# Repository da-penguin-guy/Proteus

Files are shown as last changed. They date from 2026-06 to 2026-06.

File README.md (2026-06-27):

# The Proteus

The Proteus is a modular collection of PCBs that will be used to develop the Virgil sound Protocol

Formerly known as the Virgil Controller, the Proteus is named after Proteus, a minor god from greek mythology. I chose this name because in Virgil's Georgics, he rapidly changes form, similar to how the Proteus is fully modular and can change quickly.

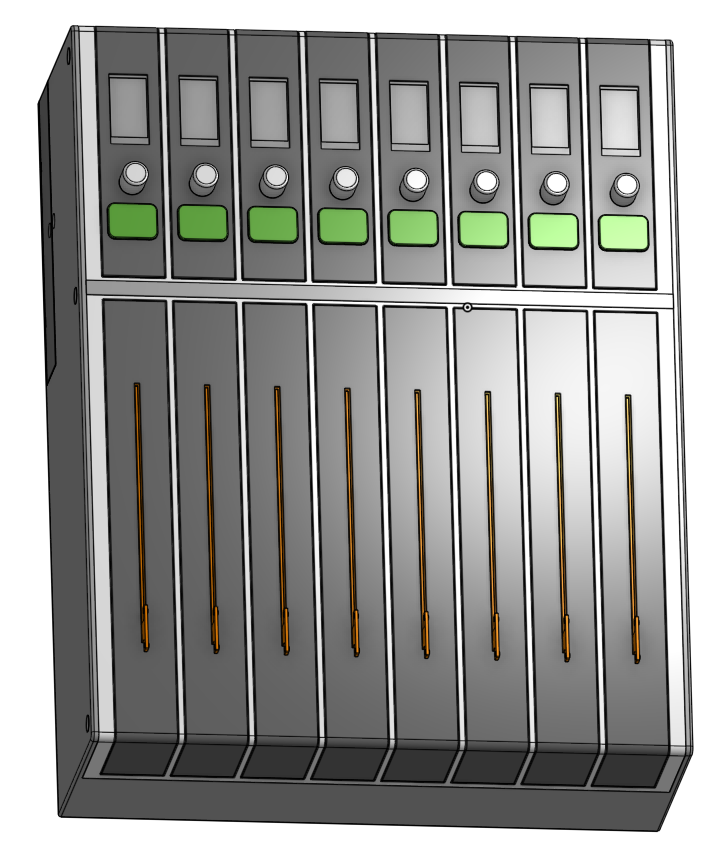
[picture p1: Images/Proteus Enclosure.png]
Proteus Enclosure


## Overview

The Proteus doesn't fall into a good product class, primarily because this hasn't ever been done before. The best analog would be some midi controller, like the [Behringer X-touch](https://www.behringer.com/en/products/0808-AAE). However, this varies from that in several cases. Firstly, it will be fully open source, modular, and future proof. The other main difference is that it won't be using the MIDI protocol. I will be using this as a hardware prototype to develop the [Virgil](https://github.com/da-penguin-guy/Virgil) live sound protocol. 

The Virgil protocol is a companion protocol to Audinate's Dante protocol, the industry standard for live audio transfer via a network. However, there is a significant gap in Dante: It only encompasses the audio transportation, not any additional communication. This is especially important for digital stageboxes, where the mixer *needs* control over physical hardware controls such as gain and phantom power. Because Dante doesn't allow for control packets, every popular audio company has created their own proprietary standard for transporting the information. This means that, despite Dante's goal of allowing for equipment from different companies to work together, productions are still limited to a single brand if they want a functional ecosystem. 

The Virgil protocol solves this by being a universal language, allowing a variety of interconnectivity.

## Modules

Cursor: Motor
Speculum: Screen
Ordo: Button

The controller itself has 16 module slots, 8 on the bottom and 8 on the top. Electrically, the slots are identical, but the slots have different lengths.

All modules (at this time) must have an rp2040/2350 microcontroller in them, and all communication over SPI.

Currently, the only module for the top slot is a display module that has a 1.14" TFT display, a button with a neopixel, and a continuous encoder with a neopixel. The display is the same as the [Adafruit Newxie Tube](https://www.adafruit.com/product/6113), but just the panel can be found on [AliExpress](https://www.aliexpress.com/i/3256803593005387.html?gatewayAdapt=4itemAdapt#nav-description) for significantly cheaper. For more information, go to the [Proteus Speculum](PCB/Proteus%20Speculum/Virgil%20Screen.kicad_pro) kicad project.

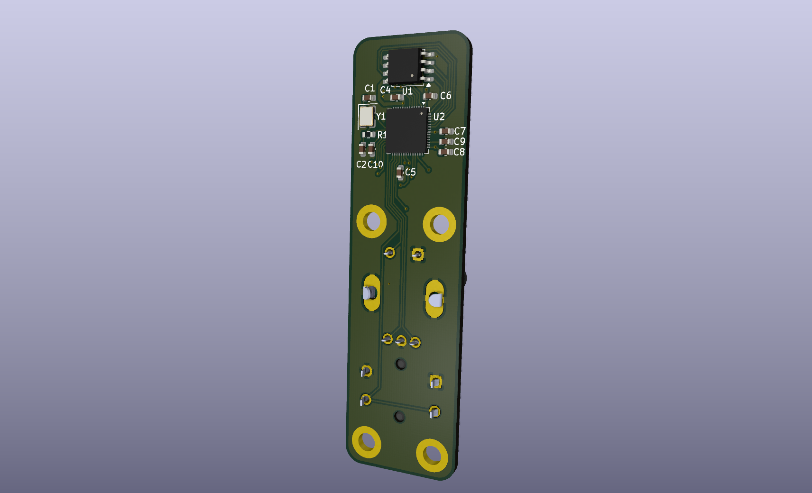
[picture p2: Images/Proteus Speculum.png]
Proteus Speculum Rendering


Currently, the only module for the bottom slot is a motorized fader using the B103 fader. These are the same faders used in the [Behringer X-Touch](https://www.sweetwater.com/store/detail/XTOUCHFADER--behringer-mf100t-motorized-faders-set-of-5-for-by-touch-series), but they can be found for significantly cheaper on [Alibaba](https://www.alibaba.com/product-detail/Toy-Sound-Box-Variable-Resistors-Fader_1601226018682.html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). For more information, go to the [Proteus Cursor](PCB/Proteus%20Cursor/Virgil%20Motor.kicad_pro) kicad project.

## Internal PCBs

The Proteus has 3 internal PCBs: The [Motherboard](#motherboard), The [Power](#power) Board, and The [Backplane](#backplane).

### Motherboard
This is the actual brain of the device.

For external ports, it has an Ethercon port for networking and a USB-C port for programming.  

For Internal ports, it has 2 50 pin IDC connectors, each with different pinouts. The first connects to the Power board and the second connects to the Backplane. The power board connects directly to the Controller, while the backplane connects via an IDC cable. There is also a microSD card connected via SDIO for icon storage.

For ICs the controller has an RP2350. It also has a W5500 for ethernet connectivity and the Raspberry Pi Radio Module 2 for wireless connectivity

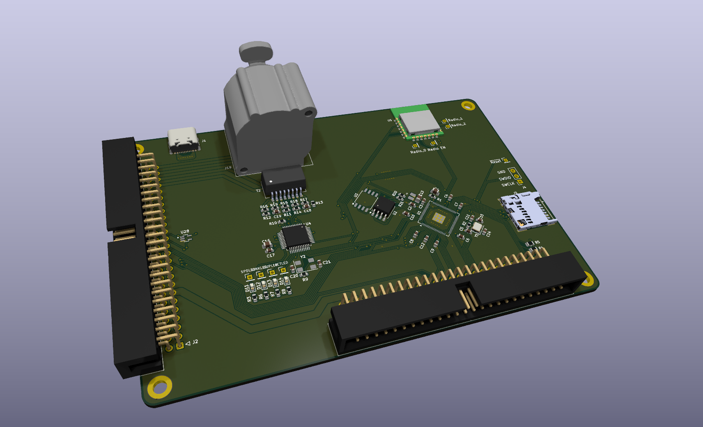
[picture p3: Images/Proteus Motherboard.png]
Proteus Motherboard Rendering


### Power
The power module is designed to be completely separated and isolated from the main board. This is primarily because I want for this to eventually have a battery powered option, but I don't want to deal with a BMS yet. 

The power module is expected to supply 3.3V, 5V, and a currently unknown motor VCC (somewhere between 9-12V). Motor VCC and current requirements will be determined after testing

Power modules are given a space on the back of the enclosure to expose their own power connectors. In addition, all the required signals for POE and USB-C PD are passed from the controller to the power board, including USB-C CC lines.

Currently, the only power module that has been developed supports POE and 12V in through a barrel jack. This power module is designed to be for very early prototyping. Because of that, the current module has an RP2350 on it, combined with current and voltage sensing on all lines. In addition, the motor VCC also has a smart power fuse and adjustable voltage via a DigiPot.

### Backplane
The backplane is the PCB that the modules plug into. This is kept separate so that extra module slots may be added in the future, and for simplifying enclosure design. 

The main purpose of the backplane is to route connections from the 50 pin connector to the controller and each of the 16 modules. The signals that are being routed are various power lines, spi, SWD, and one singular GPIO. That gpio is tied directly to the controller, and was intended as an SPI interrupt. However, that will likely be removed in future iterations to allow for better scaling across more modules.

The backplane does have some ICs on it. The most notable is a CD74HC154M96, used to split the 4 CS mux lines from the controller to 16 CS lines for the modules. There are also 2 MCP23017T-E/SS I2C expanders, used for supplying reset lines to the modules and detect lines. The backplane also has 16 SN74CBTLV1G125DCKR, one for each module. This is used to switch the SWD lines on or off for each module, using the CS line as the control signal. This is so that the controller can program every module automatically.

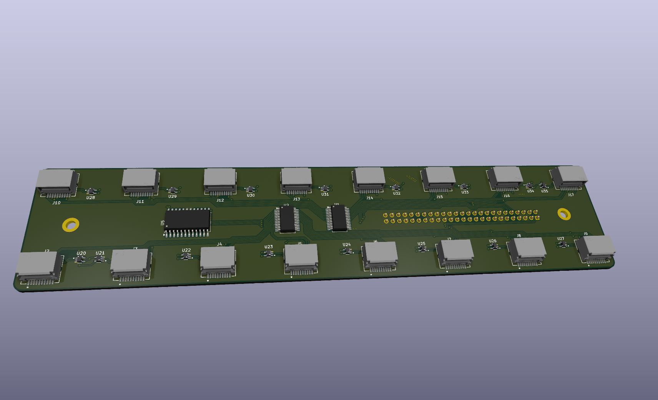
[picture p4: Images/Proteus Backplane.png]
Proteus Backplane Rendering


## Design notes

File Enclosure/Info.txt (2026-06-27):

All 3d models were made in onshape. The link can be found here: https://cad.onshape.com/documents/d399654ec14494d1790123eb/w/8a950a518b7c39473549627b/e/b128ff8ea3088b92f5d37e80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

The size of all heat set inserts can be adjusted in the variable studio.

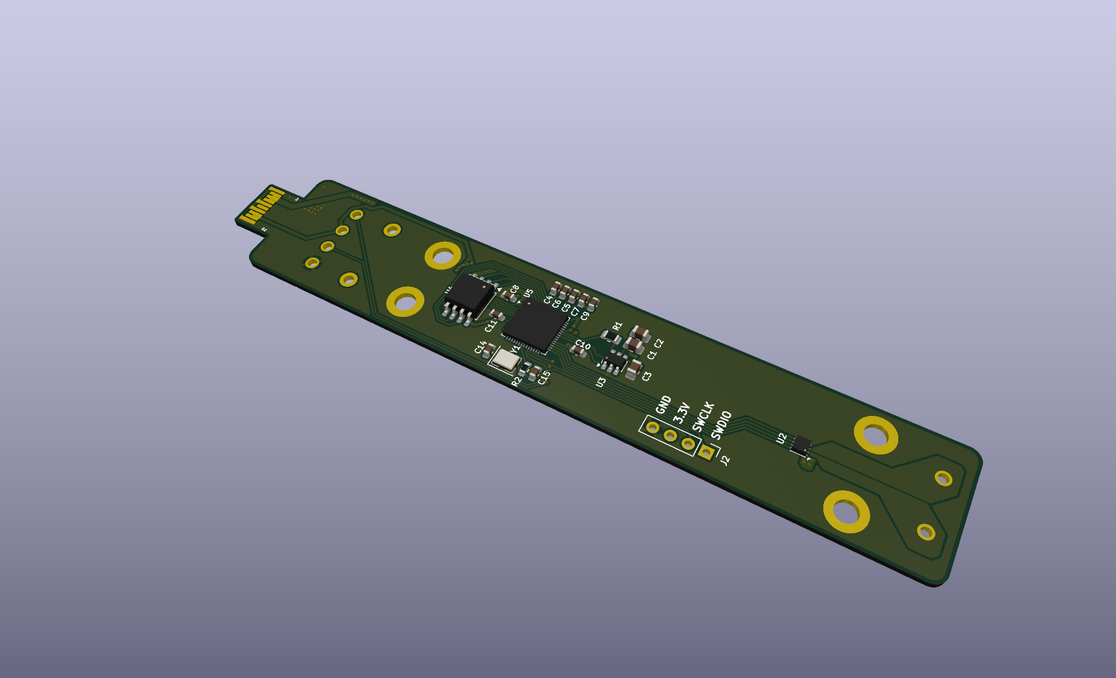
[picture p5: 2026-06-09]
Images/Proteus Cursor.png

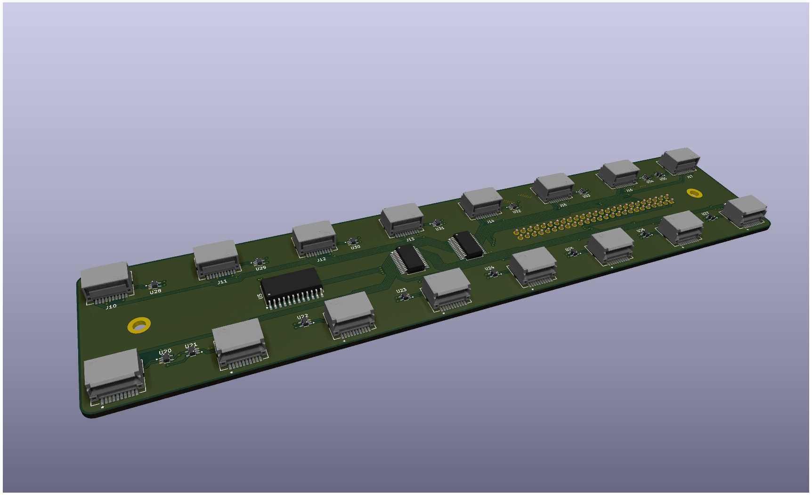
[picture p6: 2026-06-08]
PCB/Proteus Backplane/render.png

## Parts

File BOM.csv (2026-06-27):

Name | Count | Category | File/Link
Proteus Motherboard | 1 | PCB | PCB\Proteus Motherboard
Proteus Backplane | 1 | PCB | PCB\Proteus Backplane
Proteus Power | 1 | PCB | PCB\Proteus Power
Proteus Spectulum | 8 | PCB | PCB\Proteus Speculum
Ribbon Adaptor | 8 | PCB | PCB\Ribbon Adaptor
Proteus Cursor | 8 | PCB | PCB\Proteus Cursor
1.14" TFT Display | 8 | Non PCB Electronics | https://www.aliexpress.com/i/3256803593005387.html?gatewayAdapt=4itemAdapt#nav-description
Base | 1 | Enclosure | Enclosure\Part Studio 1.step
Power Slide | 1 | Enclosure | Enclosure\Part Studio 1.step
Lock Pin | 1 | Enclosure | Enclosure\Part Studio 1.step
Fader Rail | 1 | Enclosure | Enclosure\Part Studio 1.step
Midplate | 1 | Enclosure | Enclosure\Part Studio 1.step
Screen Rail | 1 | Enclosure | Enclosure\Part Studio 1.step
Fader Container Lid | 8 | Enclosure | Enclosure\Part Studio 1.step
Fader Container | 8 | Enclosure | Enclosure\Part Studio 1.step
Screen Container Lid | 8 | Enclosure | Enclosure\Part Studio 1.step
Screen Container | 8 | Enclosure | Enclosure\Part Studio 1.step
Knob | 8 | Enclosure | Enclosure\Part Studio 1.step
Button | 8 | Enclosure | Enclosure\Part Studio 1.step
Display Case | 8 | Enclosure | Enclosure\Virgil Screen.step
M3x5x5 Heat set insert | 198 | Part
M3 Countersunk screw | 198 | Part

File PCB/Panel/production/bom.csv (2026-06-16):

Designator | Footprint | Quantity | Value | LCSC Part #
C1, C11, C13, C2, C24, C26, C33, C34 | 0603 | 8 | 15pF
C10, C12, C14, C15, C16, C17, C18, C19, C20, C21, C22, C23, C25, C27, C28, C29, C3, C30, C31, C32, C35, C36, C37, C38, C4, C5, C6, C7, C8, C9 | 0603 | 30 | 100nF
D1, D2, D3, D4 | LED_SK6812MINI_PLCC4_3.5x3.5mm_P1.75mm | 4 | SK6812MINI
J1, J2, J3, J4 | JUSHUO AFC07-S20FCC-00 | 4 | AFC07-S20FCC-00
J10, J9 | PinHeader_1x04_P2.54mm_Vertical | 2 | Conn_01x04_Pin
J5, J6, J7, J8 | 10056847-101LF-EDGE | 4 | 10056847-101LF
Q1, Q2 | SOT-23 | 2 | SS8550
R1, R2, R3, R4 | 0603 | 4 | 1kΩ
S1, S2 | XDCR_PEC12R-4225F-S0024 | 2 | PEC12R-4225F-S0024
S3, S4 | SW_B3F-4055 | 2 | B3F-4055
U1, U2 | SOT-23-6 | 2 | SN74LVC1T45DBV
U10, U9 | WSON-8-1EP_2x2mm_P0.5mm_EP0.9x1.6mm_ThermalVias | 2 | DRV8220DSG
U11, U12, U15, U16 | QFN-56-1EP_7x7mm_P0.4mm_EP3.2x3.2mm | 4 | RP2040
U13, U14 | SOIC8_4P9X3P9MC_MCH-L | 2 | CAP1293-1-SN-TR
U17, U18, U7, U8 | SOIC-8_5.3x5.3mm_P1.27mm | 4 | W25Q16JVSS
U3, U4 | B103 | 2 | B103
U5, U6 | Display Connector | 2 | AFC07-S08ECC-00
Y1, Y2, Y3, Y4 | Crystal_SMD_Abracon_ABM8G-4Pin_3.2x2.5mm | 4 | ABM8-272-T3

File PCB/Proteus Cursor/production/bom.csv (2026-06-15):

Designator | Footprint | Quantity | Value | LCSC Part #
C10, C11, C4, C5, C6, C7, C8, C9 | 0603 | 8 | 100nF
C14, C15 | 0603 | 2 | 15pF
J1 | 10056847-101LF-EDGE | 1 | 10056847-101LF
J2 | PinHeader_1x04_P2.54mm_Vertical | 1 | Conn_01x04_Pin
R2 | 0603 | 1 | 1kΩ
U1 | B103 | 1 | B103
U2 | WSON-8-1EP_2x2mm_P0.5mm_EP0.9x1.6mm_ThermalVias | 1 | DRV8220DSG
U3 | SOIC8_4P9X3P9MC_MCH-L | 1 | CAP1293-1-SN-TR
U4 | SOIC-8_5.3x5.3mm_P1.27mm | 1 | W25Q16JVSS
U5 | QFN-56-1EP_7x7mm_P0.4mm_EP3.2x3.2mm | 1 | RP2040
Y1 | Crystal_SMD_Abracon_ABM8G-4Pin_3.2x2.5mm | 1 | ABM8-272-T3

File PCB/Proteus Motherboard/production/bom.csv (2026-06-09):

Designator | Footprint | Quantity | Value | LCSC Part #
C1, C13, C16 | 0805 | 3 | 4.7uF
C10, C11, C12, C17, C18, C2, C3, C4, C5, C6, C7, C8, C9 | 0603 | 13 | .1uF
C14, C15 | 0603 | 2 | 15pF
C19 | 0603 | 1 | 22nF
C20, C21 | 0603 | 2 | 18pF
D11, D12, D13, D14 | 0603 | 4 | LED
J1 | USB_C_Receptacle_GCT_USB4105-xx-A_16P_TopMnt_Horizontal | 1 | USB_C_Receptacle_USB2.0_16P
J19 | NEUTRIK_NE8FAH | 1 | NE8FAH
J2 | IDC-Header_2x25_P2.54mm_Horizontal | 1 | Conn_02x25_Odd_Even
J3 | MOLEX_503398-1892 | 1 | 503398-1892
J4 | PinSocket_1x03_P2.54mm_Vertical | 1 | Conn_01x03_Pin
J6 | IDC-Header_2x25_P2.54mm_Horizontal | 1 | SBH11-PBPC-D25-RA-BK
L1 | 0806 | 1 | AOTA-B201610S3R3-101-T
R1 | 0603 | 1 | 33Ω
R10 | 0603 | 1 | 12.4kΩ
R11, R12, R13, R14 | 0603 | 4 | 3.3Ω
R15, R16, R17, R18 | 0603 | 4 | 49.9kΩ
R19 | 0603 | 1 | 10Ω
R2 | 0603 | 1 | 1kΩ
R20, R21 | 0603 | 2 | 27Ω
R3, R6, R7, R8 | 0603 | 4 | 68Ω
R4, R5 | 0805 | 2 | 4.7Ω
R9 | 0603 | 1 | 1MΩ
T2 | XFMR_PT61018PEL | 1 | PT61018PEL
TP10 | PinHeader_1x01_P2.00mm_Vertical | 1 | Radio EN
TP11 | PinHeader_1x01_P2.00mm_Vertical | 1 | Radio_2
TP12 | PinHeader_1x01_P2.00mm_Vertical | 1 | Radio_1
TP15 | PinHeader_1x01_P2.00mm_Vertical | 1 | SPDLED
TP16 | PinHeader_1x01_P2.00mm_Vertical | 1 | LINKLED
TP17 | PinHeader_1x01_P2.00mm_Vertical | 1 | DUPLED
TP18 | PinHeader_1x01_P2.00mm_Vertical | 1 | ACTLED
TP78 | PinHeader_1x01_P2.00mm_Vertical | 1 | ~{Reset}
TP9 | PinHeader_1x01_P2.00mm_Vertical | 1 | Radio_0
U1 | QFN-80-1EP_10x10mm_P0.4mm_EP3.4x3.4mm | 1 | RP2350B
U2, U3 | SOIC-8_5.3x5.3mm_P1.27mm | 2 | W25Q16JVSS
U28 | SOT65P210X110-5N | 1 | SN74CBTLV1G125DCKR
U4 | LQFP-48_7x7mm_P0.5mm | 1 | W5500
U5 | rpi_rmc20452t | 1 | SC1169
Y1 | Crystal_SMD_Abracon_ABM8G-4Pin_3.2x2.5mm | 1 | ABM8-272-T3
Y2 | Crystal_SMD_Abracon_ABM3C-4Pin_5.0x3.2mm | 1 | ABM3C-25.000MHZ-D4Y-T

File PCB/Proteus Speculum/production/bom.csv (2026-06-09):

Designator | Footprint | Quantity | Value | LCSC Part #
C1, C2 | 0603 | 2 | 15pF
C10, C4, C5, C6, C7, C8, C9 | 0603 | 7 | 100nF
D1, D2 | LED_SK6812MINI_PLCC4_3.5x3.5mm_P1.75mm | 2 | SK6812MINI
J2 | AMPHENOL_SFV20R-2STE1HLF | 1 | AFC07-S20FCC-00
Q1 | SOT-23 | 1 | SS8550
R1 | 0603 | 1 | 1kΩ
S1 | XDCR_PEC12R-4225F-S0024 | 1 | PEC12R-4225F-S0024
S2 | SW_B3F-4055 | 1 | B3F-4055
U1 | SOIC-8_5.3x5.3mm_P1.27mm | 1 | W25Q16JVSS
U2 | QFN-56-1EP_7x7mm_P0.4mm_EP3.2x3.2mm | 1 | RP2040
U3 | SOT-23-6 | 1 | SN74LVC1T45DBV
U4 | Display Connector | 1 | AFC07-S08ECC-00
Y1 | Crystal_SMD_Abracon_ABM8G-4Pin_3.2x2.5mm | 1 | ABM8-272-T3

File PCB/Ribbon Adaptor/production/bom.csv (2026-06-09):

Designator | Footprint | Quantity | Value | LCSC Part #
J1 | 10056847-101LF-EDGE | 1 | 10056847-101LF
J2 | AMPHENOL_SFV20R-2STE1HLF | 1 | AFC07-S20FCC-00

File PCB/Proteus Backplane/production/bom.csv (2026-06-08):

Designator | Footprint | Quantity | Value | LCSC Part #
J1 | IDC-Header_2x25_P2.54mm_Vertical | 1 | SBH11-PBPC-D25-RA-BK
J10, J11, J12, J13, J14, J15, J16, J17, J2, J3, J4, J5, J6, J7, J8, J9 | CONN_10056847-101LF_AMP | 16 | 10056847-101LF
U1, U2 | SSOP-28_5.3x10.2mm_P0.65mm | 2 | MCP23017T-E/SS
U20, U21, U22, U23, U24, U25, U26, U27, U28, U29, U30, U31, U32, U33, U34, U35 | SOT65P210X110-5N | 16 | SN74CBTLV1G125DCKR
U5 | SOIC-24W_7.5x15.4mm_P1.27mm | 1 | CD74HC154M96

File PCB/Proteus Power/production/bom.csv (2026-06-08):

Designator | Footprint | Quantity | Value | LCSC Part #
C1, C10, C11, C12, C13, C14, C16, C18, C20, C21, C22, C24, C26, C27, C4, C6, C7, C8, C9 | 1206 | 19 | 10uF
C15, C17, C19, C2, C25, C3, C5 | 0603 | 7 | .1uF
C23 | CP_Radial_D10.0mm_P5.00mm | 1 | 1mF
D1, D2, D3, D4, D5, D6, D7, D8 | D_DO-15_P12.70mm_Horizontal | 8 | D_Schottky
J2 | BarrelJack_Horizontal | 1 | Barrel_Jack_MountingPin
J3 | CONN_SFH11-PBPC-D25-RA-BK_50P_SUL | 1 | Conn_02x25_Odd_Even
L1, L2, L3 | IND_PA4342_PUL-L | 3 | 4.7uH
R1 | 0603 | 1 | 52.3kΩ
R10, R13 | 2512 | 2 | 10mΩ
R11 | 2512 | 1 | 20mΩ
R12 | 2010 | 1 | 50mΩ
R14, R3, R7, R8 | 0603 | 4 | 10kΩ
R2 | 0603 | 1 | 30.9kΩ
R4 | 0603 | 1 | 102kΩ
R5, R6 | 0603 | 2 | 5.1kΩ
R9 | 0603 | 1 | 100kΩ
U1, U2, U4 | SOT-583-8 | 3 | TPS563300
U10, U12, U3, U8 | VSSOP-10_3x3mm_P0.5mm | 4 | INA226
U11, U9 | SO-4_4.4x3.6mm_P2.54mm | 2 | LTV-356T
U13 | TO-252-4 | 1 | BTS50080-1TEA
U5 | MODULE_AG59612-LPB | 1 | AG59612-LPB
U6 | XIAO-RP2040-SMD | 1 | XIAO-RP2040-SMD
U7 | MSOP-8_3x3mm_P0.65mm | 1 | MCP4562T-503E/MF

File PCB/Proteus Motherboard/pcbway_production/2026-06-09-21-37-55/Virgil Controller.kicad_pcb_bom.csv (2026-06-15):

Designator | Quantity | Value | Footprint | Package | MPN | DNP | Mount_Type | Description | KiLib_Generator | Sim.Pins | MF | MAXIMUM_PACKAGE_HEIGHT | Price | Check_prices | STANDARD | PARTREV | SnapEDA_Link | MP | Description_1 | MANUFACTURER | Availability | SNAPEDA_PN | DigiKey_Part_Number
C1, C13, C16 | 3 | 4.7uF | C_0805_2012Metric |  |  |  | smt | Unpolarized capacitor | SMD_2terminal_chip_molded
C10, C11, C12, C17, C18, C2, C3, C4, C5, C6, C7, C8, C9 | 13 | .1uF | C_0603_1608Metric |  |  |  | smt | Unpolarized capacitor | SMD_2terminal_chip_molded
C14, C15 | 2 | 15pF | C_0603_1608Metric |  |  |  | smt | Unpolarized capacitor | SMD_2terminal_chip_molded
C19 | 1 | 22nF | C_0603_1608Metric |  |  |  | smt | Unpolarized capacitor | SMD_2terminal_chip_molded
C20, C21 | 2 | 18pF | C_0603_1608Metric |  |  |  | smt | Unpolarized capacitor | SMD_2terminal_chip_molded
D11, D12, D13, D14 | 4 | LED | LED_0603_1608Metric |  |  |  | smt | Light emitting diode | SMD_2terminal_chip_molded | 1=K 2=A
J1 | 1 | USB_C_Receptacle_USB2.0_16P | USB_C_Receptacle_GCT_USB4105-xx-A_16P_TopMnt_Horizontal |  |  |  | smt | USB 2.0-only 16P Type-C Receptacle connector
J19 | 1 | NE8FAH | NEUTRIK_NE8FAH | None |  |  | tht |  |  |  | Neutrik | 25.00mm | None | https://www.snapeda.com/parts/NE8FAH/Neutrik/view-part/?ref=eda | Manufacturer Recommendations | 16.04.02 | https://www.snapeda.com/parts/NE8FAH/Neutrik/view-part/?ref=snap | NE8FAH | Horizonal PCB mount RJ45 receptacle, A-Series cutout with latch lock, max | Neutrik | In Stock | NE8FAH
J2 | 1 | Conn_02x25_Odd_Even | IDC-Header_2x25_P2.54mm_Horizontal |  |  |  | tht | Generic connector, double row, 02x25, odd/even pin numbering scheme (row 1 odd numbers, row 2 even numbers), script generated (kicad-library-utils/schlib/autogen/connector/)
J3 | 1 | 503398-1892 | MOLEX_503398-1892 |  |  |  | smt |  |  |  |  |  |  |  | MANUFACTURER RECOMMENDATIONS | 0 |  |  |  | molex
J4 | 1 | Conn_01x03_Pin | PinSocket_1x03_P2.54mm_Vertical |  |  | Yes | tht | Generic connector, single row, 01x03, script generated | connector/pin_header_socket
J6 | 1 | SBH11-PBPC-D25-RA-BK | IDC-Header_2x25_P2.54mm_Horizontal |  |  |  | tht | Generic connector, double row, 02x25, top/bottom pin numbering scheme (row 1: 1...pins_per_row, row2: pins_per_row+1 ... num_pins), script generated (kicad-library-utils/schlib/autogen/connector/)
L1 | 1 | AOTA-B201610S3R3-101-T | 0806 |  |  |  | smt | Inductor
R1 | 1 | 33Ω | R_0603_1608Metric |  |  |  | smt | Resistor, US symbol | SMD_2terminal_chip_molded
R10 | 1 | 12.4kΩ | R_0603_1608Metric |  |  |  | smt | Resistor, US symbol | SMD_2terminal_chip_molded
R11, R12, R13, R14 | 4 | 3.3Ω | R_0603_1608Metric |  |  |  | smt | Resistor, US symbol | SMD_2terminal_chip_molded
R15, R16, R17, R18 | 4 | 49.9kΩ | R_0603_1608Metric |  |  |  | smt | Resistor, US symbol | SMD_2terminal_chip_molded
R19 | 1 | 10Ω | R_0603_1608Metric |  |  |  | smt | Resistor, US symbol | SMD_2terminal_chip_molded
R2 | 1 | 1kΩ | R_0603_1608Metric |  |  |  | smt | Resistor, US symbol | SMD_2terminal_chip_molded
R20, R21 | 2 | 27Ω | R_0603_1608Metric |  |  |  | smt | Resistor, US symbol | SMD_2terminal_chip_molded
R3, R6, R7, R8 | 4 | 68Ω | R_0603_1608Metric |  |  |  | smt | Resistor, US symbol | SMD_2terminal_chip_molded
R4, R5 | 2 | 4.7Ω | R_0805_2012Metric |  |  |  | smt | Resistor, US symbol | SMD_2terminal_chip_molded
R9 | 1 | 1MΩ | R_0603_1608Metric |  |  |  | smt | Resistor, US symbol | SMD_2terminal_chip_molded
T2 | 1 | PT61018PEL | XFMR_PT61018PEL |  |  |  | smt |  |  |  |  | 5.65 mm |  |  | Manufacturer Recommendations | 05/14 |  |  |  | Bourns
TP10 | 1 | Radio EN | PinHeader_1x01_P2.00mm_Vertical |  |  | Yes | tht | test point
TP11 | 1 | Radio_2 | PinHeader_1x01_P2.00mm_Vertical |  |  | Yes | tht | test point
TP12 | 1 | Radio_1 | PinHeader_1x01_P2.00mm_Vertical |  |  | Yes | tht | test point
TP15 | 1 | SPDLED | PinHeader_1x01_P2.00mm_Vertical |  |  | Yes | tht | test point | connector/pin_header_socket
TP16 | 1 | LINKLED | PinHeader_1x01_P2.00mm_Vertical |  |  | Yes | tht | test point | connector/pin_header_socket
TP17 | 1 | DUPLED | PinHeader_1x01_P2.00mm_Vertical |  |  | Yes | tht | test point | connector/pin_header_socket
TP18 | 1 | ACTLED | PinHeader_1x01_P2.00mm_Vertical |  |  | Yes | tht | test point | connector/pin_header_socket
TP78 | 1 | ~{Reset} | PinHeader_1x01_P2.00mm_Vertical |  |  | Yes | tht | test point | connector/pin_header_socket
TP9 | 1 | Radio_0 | PinHeader_1x01_P2.00mm_Vertical |  |  | Yes | tht | test point
U1 | 1 | RP2350B | QFN-80-1EP_10x10mm_P0.4mm_EP3.4x3.4mm |  |  |  | smt | A microcontroller by Raspberry Pi, dual CPU architecture (ARM Cortex-M33 / RISC-V Hazard3), 150MHz, no flash, 520KB SRAM, 12 PIO state machines, VQFN-80 | package/no_lead
U2 | 1 | W25Q16JVSS | SOIC-8_5.3x5.3mm_P1.27mm |  |  |  | smt | 16Mbit / 2MiB Serial Flash Memory, Standard/Dual/Quad SPI, 2.7-3.6V, SOIC-8 (208 mil) | package/gullwing
U28 | 1 | SN74CBTLV1G125DCKR | SOT65P210X110-5N | SC70-5 Texas Instruments |  |  | smt |  |  |  | Texas Instruments |  |  | https://www.snapeda.com/parts/SN74CBTLV1G125DCKR/Texas+Instruments/view-part/?ref=eda |  |  | https://www.snapeda.com/parts/SN74CBTLV1G125DCKR/Texas+Instruments/view-part/?ref=snap | SN74CBTLV1G125DCKR | 3.3-V, 1:1 (SPST), 1-channel FET bus switch |  |  |  | 296-9110-1-ND
U3 | 1 | W25Q16JVSS | SOIC-8_5.3x5.3mm_P1.27mm |  |  | Yes | smt | 16Mbit / 2MiB Serial Flash Memory, Standard/Dual/Quad SPI, 2.7-3.6V, SOIC-8 (208 mil) | package/gullwing
U4 | 1 | W5500 | LQFP-48_7x7mm_P0.5mm |  |  |  | smt | 10/100Mb SPI Ethernet controller with TCP/IP stack, LQFP-48 | package/gullwing
U5 | 1 | SC1169 | rpi_rmc20452t |  |  |  | smt
Y1 | 1 | ABM8-272-T3 | Crystal_SMD_Abracon_ABM8G-4Pin_3.2x2.5mm |  |  |  | smt | Four pin crystal, GND on pins 2 and 4 | crystal_resonator_oscillator
Y2 | 1 | ABM3C-25.000MHZ-D4Y-T | Crystal_SMD_Abracon_ABM3C-4Pin_5.0x3.2mm |  |  |  | smt | Four pin crystal, GND on pins 2 and 4 | crystal_resonator_oscillator

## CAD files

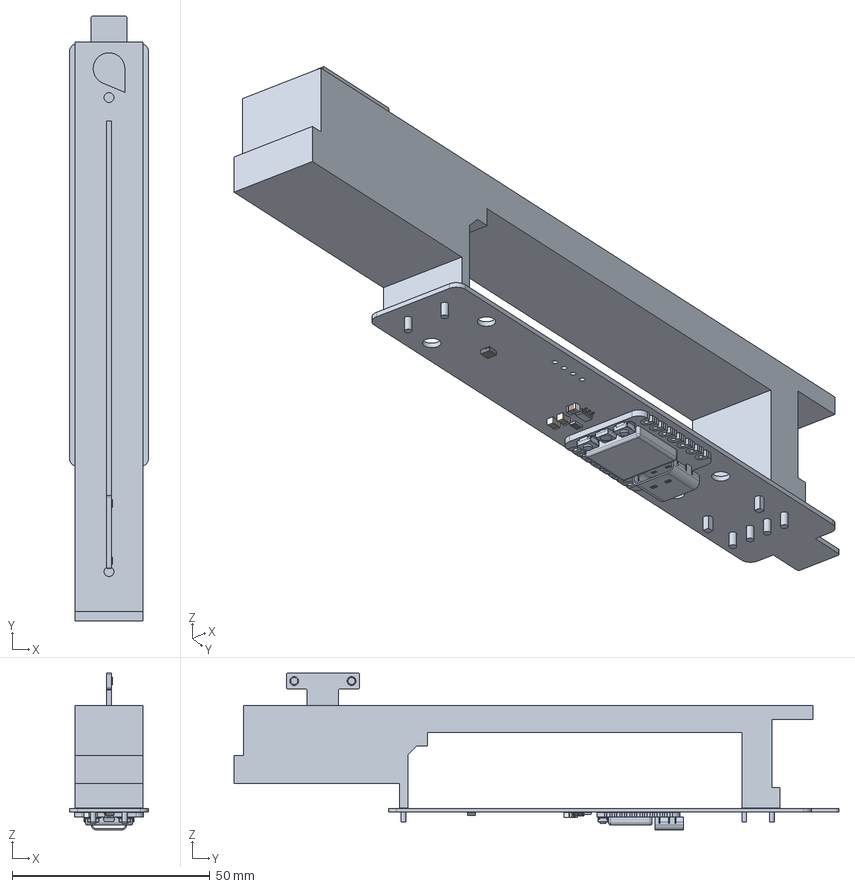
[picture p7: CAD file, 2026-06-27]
Enclosure/Virgil Motor.step
20.0 x 153.1 x 39.7 mm

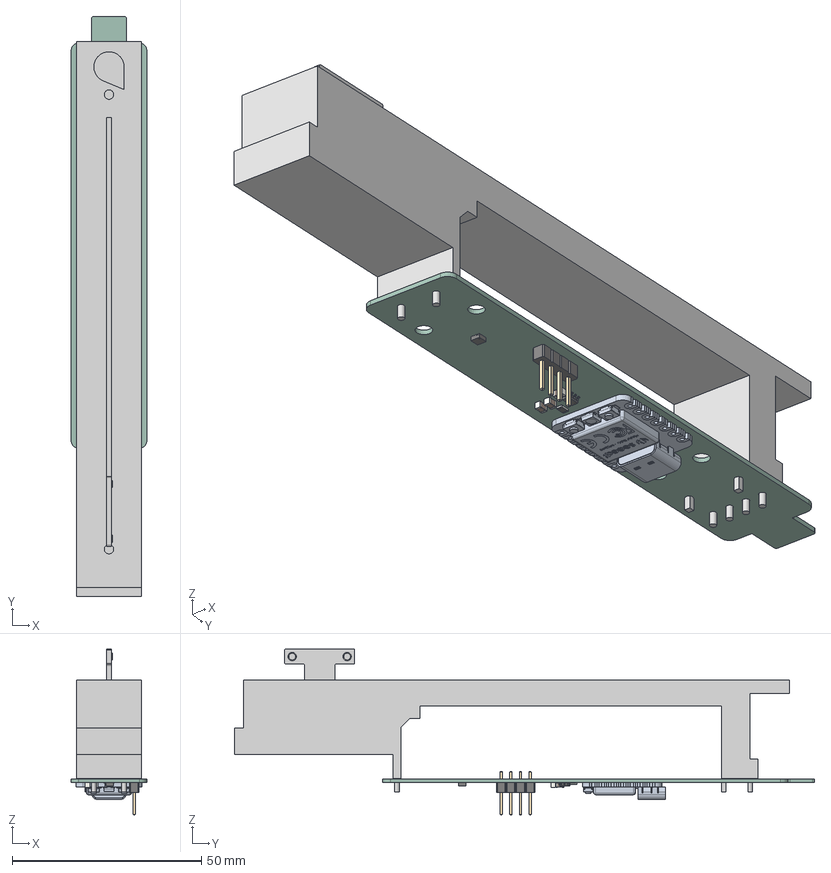
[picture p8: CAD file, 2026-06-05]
PCB/Proteus Cursor/Virgil Motor.step
20.0 x 153.1 x 43.8 mm
B103
Slider
WSON-8-1EP_2x2mm_P0.5mm_EP0.9x1.6mm
C_0805_2012Metric x 3
TSOT-23-6
R_0805_2012Metric
PinHeader_1x04_P2.54mm_Vertical
Seeed_Studio_XIAO_RP2040_v26
Virgil Motor_PCB

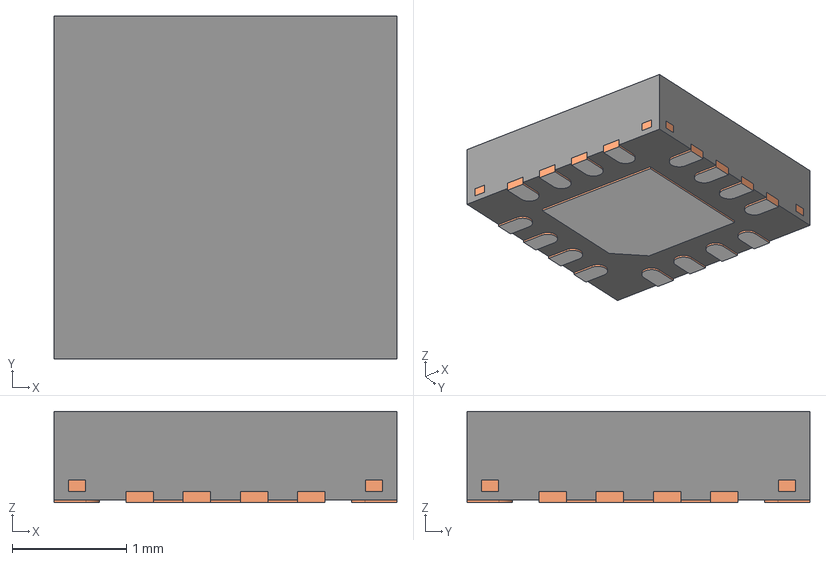
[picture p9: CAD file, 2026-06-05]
PCB/Proteus Motherboard/RTE0016C.stp
3.00 x 3.00 x 0.8 mm
BODY-QFN
FRAME-RTE0016C
PIN1-ID

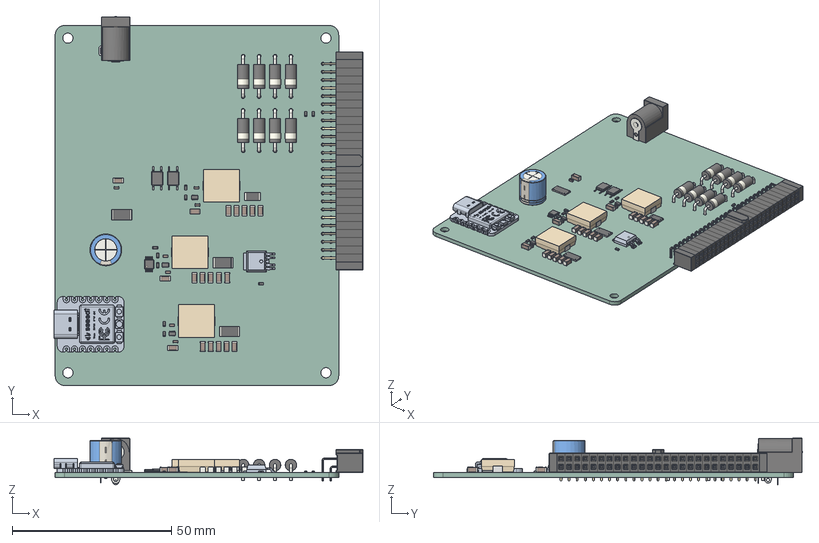
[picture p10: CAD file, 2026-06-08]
PCB/Proteus Power/Virgil Power.step
97.0 x 115.8 x 14.6 mm
C_1206_3216Metric x 19
R_0603_1608Metric x 10
D_DO-15_P12.70mm_Horizontal x 8
SOT-583-8 x 3
C_0603_1608Metric x 7
R_2512_6332Metric x 3
SO-4_4.4x3.6mm_P2.54mm x 2
IND_PA4342_PUL x 3
CP_Radial_D10.0mm_P5.00mm
MSOP-8_3x3mm_P0.65mm
Virgil Power 1.42.1
body section with RA gold pins x 169
end x 2
Polarizing Key
R_2010_5025Metric
Seeed_Studio_XIAO_RP2040_v26
BarrelJack_Horizontal
Virgil Power_PCB

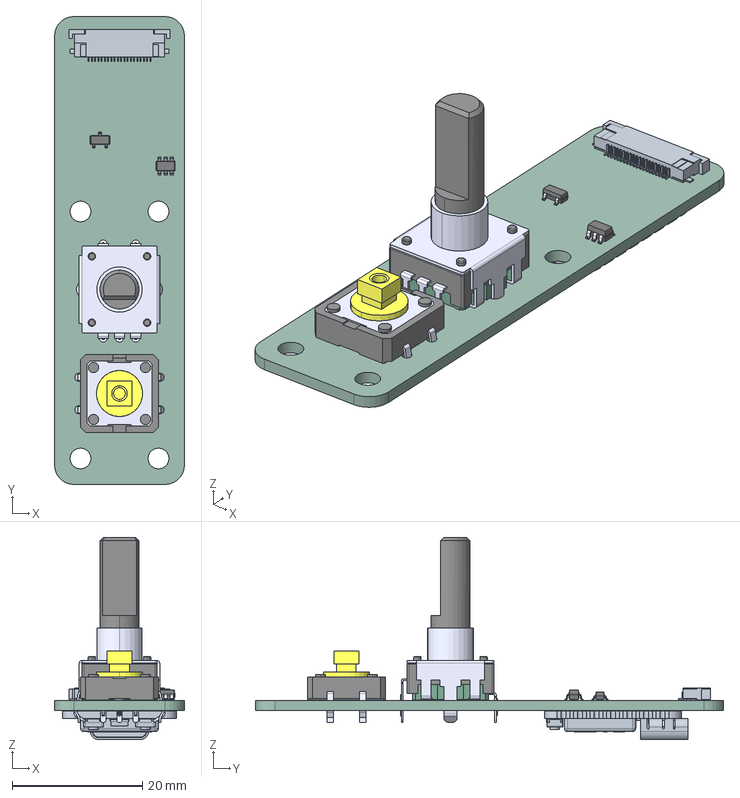
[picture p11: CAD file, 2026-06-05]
PCB/Proteus Speculum/Virgil Screen.step
20.0 x 72.0 x 31.1 mm
SOT-23-6
B3F-4055
PEC12R-4225F-S0024
SFV20R-2STE1HLF
SOT-23
Seeed_Studio_XIAO_RP2040_v26
Virgil Screen_PCB

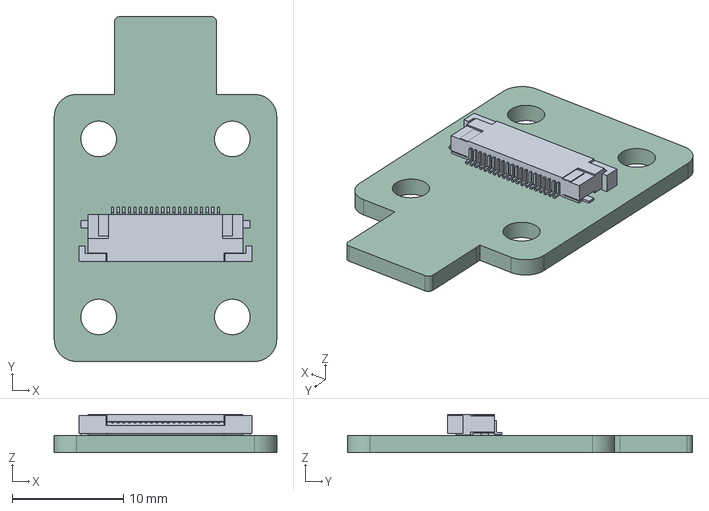
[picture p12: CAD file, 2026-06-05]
PCB/Ribbon Adaptor/Ribbon Adaptor.step
20.0 x 31.0 x 3.42 mm
SFV20R-2STE1HLF
Ribbon Adaptor_PCB

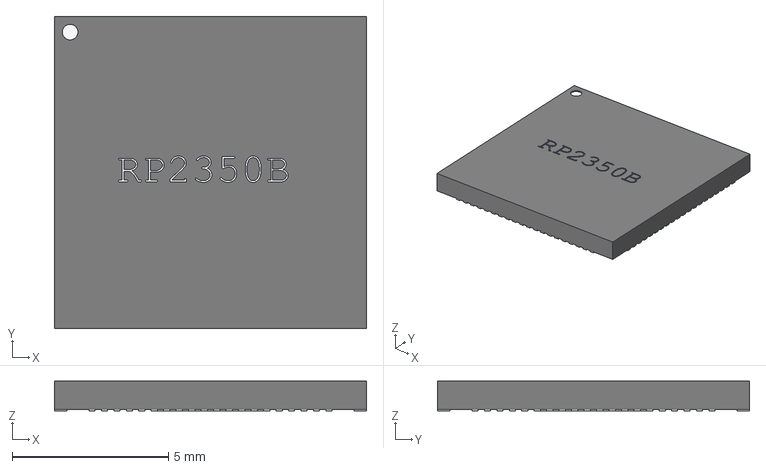
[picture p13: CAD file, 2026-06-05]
PCB/Proteus Motherboard/RP2350_QFN80.step
10.0 x 10.0 x 0.95 mm

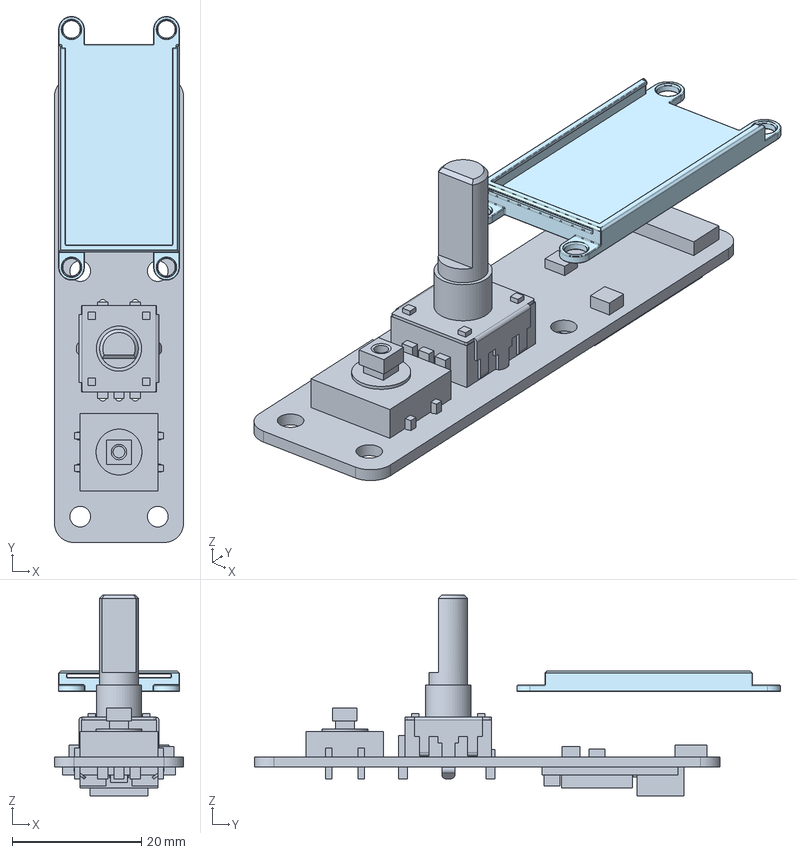
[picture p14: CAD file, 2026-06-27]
Enclosure/Virgil Screen.step
20.0 x 81.4 x 31.1 mm

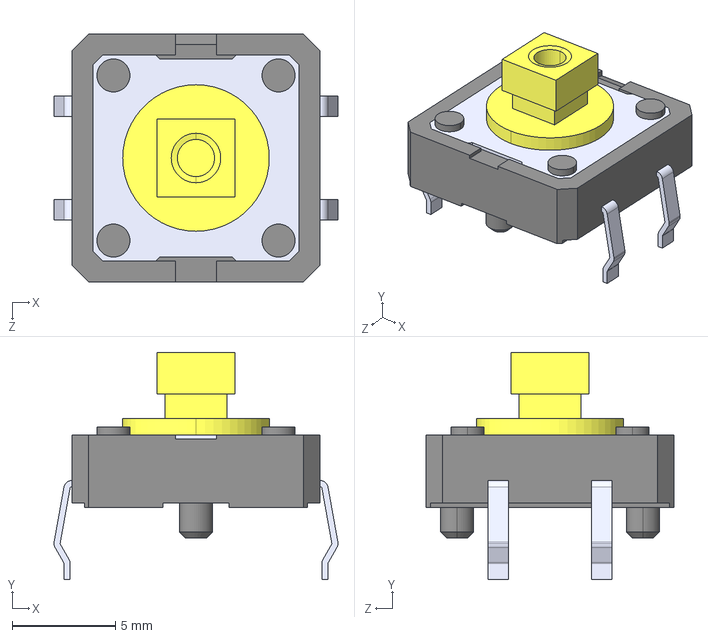
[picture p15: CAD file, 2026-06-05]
PCB/Proteus Motherboard/B3F-4055.step
13.8 x 11.0 x 12.0 mm

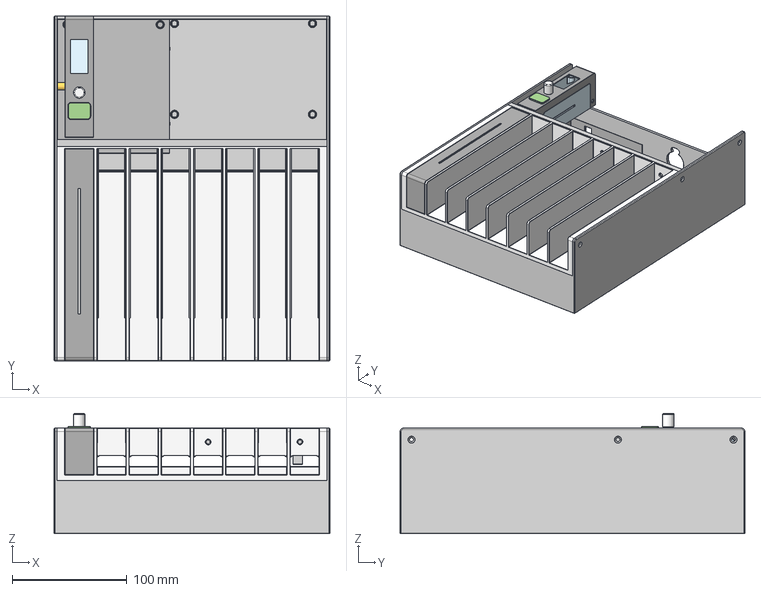
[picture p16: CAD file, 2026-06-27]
Enclosure/Part Studio 1.step
240.0 x 300.0 x 104.4 mm

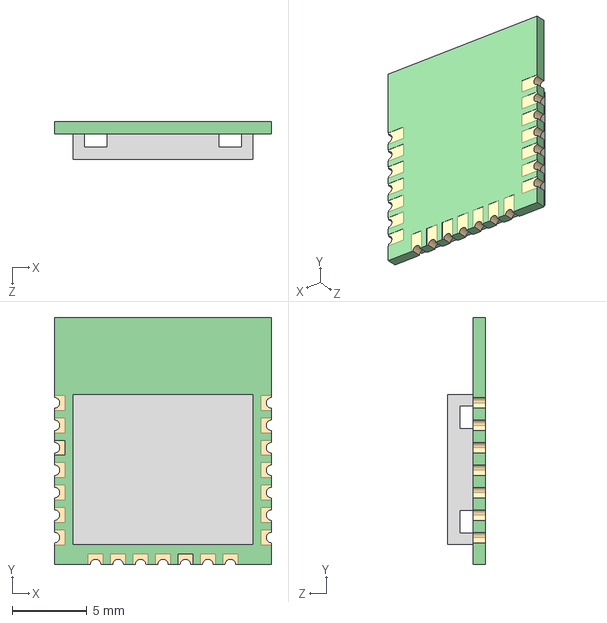
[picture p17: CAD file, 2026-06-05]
PCB/Proteus Motherboard/rpi_rmc20452t.step
14.5 x 16.5 x 2.55 mm

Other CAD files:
Enclosure/Ribbon Adaptor.step

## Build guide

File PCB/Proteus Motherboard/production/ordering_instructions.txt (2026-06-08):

Ordering Instructions:
Panel dimensions: 128.10 x 174.50 mm.
Solder Mask: Red (Default)
Silkscreen: White (Default)
Layers: 2
Finish: HASL Lead-free (Default)
Thickness: 1.6mm (Default)
Copper weight: 1oz (Default)
Minimum track width: 0.20mm (7.87mil)
Minimum via drill: 0.30mm (11.81mil)

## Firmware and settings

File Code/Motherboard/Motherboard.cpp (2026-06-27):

#include <stdio.h>
#include "pico/stdlib.h"
#include "hardware/spi.h"
#include "hardware/i2c.h"

// SPI Defines
// We are going to use SPI 0, and allocate it to the following GPIO pins
// Pins can be changed, see the GPIO function select table in the datasheet for information on GPIO assignments
#define SPI_PORT spi0
#define PIN_MISO 16
#define PIN_CS   17
#define PIN_SCK  18
#define PIN_MOSI 19

// I2C defines
// This example will use I2C0 on GPIO8 (SDA) and GPIO9 (SCL) running at 400KHz.
// Pins can be changed, see the GPIO function select table in the datasheet for information on GPIO assignments
#define I2C_PORT i2c0
#define I2C_SDA 8
#define I2C_SCL 9


int main()
{
    // SPI initialisation. This example will use SPI at 1MHz.
    spi_init(SPI_PORT, 1000*1000);
    gpio_set_function(PIN_MISO, GPIO_FUNC_SPI);
    gpio_set_function(PIN_CS,   GPIO_FUNC_SIO);
    gpio_set_function(PIN_SCK,  GPIO_FUNC_SPI);
    gpio_set_function(PIN_MOSI, GPIO_FUNC_SPI);
    
    // Chip select is active-low, so we'll initialise it to a driven-high state
    gpio_set_dir(PIN_CS, GPIO_OUT);
    gpio_put(PIN_CS, 1);
    // For more examples of SPI use see https://github.com/raspberrypi/pico-examples/tree/master/spi

    // I2C Initialisation. Using it at 400Khz.
    i2c_init(I2C_PORT, 400*1000);
    
    gpio_set_function(I2C_SDA, GPIO_FUNC_I2C);
    gpio_set_function(I2C_SCL, GPIO_FUNC_I2C);
    gpio_pull_up(I2C_SDA);
    gpio_pull_up(I2C_SCL);
    // For more examples of I2C use see https://github.com/raspberrypi/pico-examples/tree/master/i2c

    while (true) {
        printf("Hello, world!\n");
        sleep_ms(1000);
    }
}

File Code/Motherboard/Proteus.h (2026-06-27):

#ifndef _BOARDS_PROTEUS_H
#define _BOARDS_PROTEUS_H

// Flash and board information

#define PICO_FLASH_SIZE_BYTES        (16 * 1024 * 1024)

#ifndef PICO_BOARD
#define PICO_BOARD "Proteus"
#endif

// Networking SPI

#define PICO_DEFAULT_SPI             spi0
#define PICO_DEFAULT_SPI_RX_PIN      0   // NET_MISO
#define PICO_DEFAULT_SPI_TX_PIN      3   // NET_MOSI
#define PICO_DEFAULT_SPI_SCK_PIN     2   // NET_CLK

#define W5500_CS_PIN                 45 // Active-low CS pin for the W5500 Ethernet controller
#define W5500_INT_PIN                46 // Interrupt pin for the W5500 Ethernet controller
#define W5500_RST_PIN                47 // Reset pin for the W5500 Ethernet controller

#define RADIO_CS_PIN                 42 // Active-low CS pin for the RPI radio module 2
#define RADIO_INT_PIN                43 // Interrupt pin for the RPI radio module 2
#define RADIO_EN_PIN                 44 // Enable pin for the RPI radio module 2

// Module SPI

#define MODULE_SPI                   spi1
#define MODULE_MISO_PIN              8 
#define MODULE_MOSI_PIN              11
#define MODULE_CLK_PIN               10

// Module CS
#define CS_EN_PIN                    40 // Active-low enable pin for the CS demultiplexer. Pull high for no module selected.

// Power Management
#define POWER_CS_PIN                 1 // Active-low CS pin for the power management controller
#define POWER_INT_PIN                9 // Interrupt pin for the power management controller
#define POWER_RST_PIN                39 // Reset pin for the power management controller

// Swd Config
#define SWDIO_OUT_PIN                28 // SWDIO pin for programming modules.
#define SWCLK_OUT_PIN                29 // SWCLK pin for programming modules.

//I2C Configuration

#define PICO_DEFAULT_I2C             i2c1
#define PICO_DEFAULT_I2C_SDA_PIN     30 // I2C SDA pin. Only used internally, not passed to modules. Modules should use the MODULE SPI for communication, and not I2C.
#define PICO_DEFAULT_I2C_SCL_PIN     31 // I2C SCL pin. Only used internally, not passed to modules. Modules should use the MODULE SPI for communication, and not I2C.

// SD Card Configuration (4-bit SDIO Mode)
/*
Pins CLK_gpio, D1_gpio, D2_gpio, and D3_gpio are at offsets from pin D0_gpio.
The offsets are determined by sd_driver\SDIO\rp2040_sdio.pio.
    CLK_gpio = (D0_gpio + SDIO_CLK_PIN_D0_OFFSET) % 32;
    As of this writing, SDIO_CLK_PIN_D0_OFFSET is 30,
        which is -2 in mod32 arithmetic, so:
    CLK_gpio = D0_gpio -2.
    D1_gpio = D0_gpio + 1;
    D2_gpio = D0_gpio + 2;
    D3_gpio = D0_gpio + 3;
*/

#define PICO_SDIO_CLK_PIN            32 // SD card clock pin (SDIO CLK)
#define PICO_SDIO_CMD_PIN            33 // SD card command pin (SDIO CMD)
#define PICO_SDIO_D0_PIN             34 // SD card data pin 0 (SDIO D0)
#define PICO_SDIO_D1_PIN             35 // SD card data pin 1 (SDIO D1)
#define PICO_SDIO_D2_PIN             36 // SD card data pin 2 (SDIO D2)
#define PICO_SDIO_D3_PIN             37 // SD card data pin 3 (SDIO D3)
#define PICO_SDIO_DET_PIN            38 // SD card detect pin (active low when card is present)

// ==========================================
// 9. Auxiliary RAM
// ==========================================
#define RAM_CS_PIN                   41 // Active-low CS pin for the auxiliary RAM chip. This is a simple SPI RAM chip that can be used for extra storage or as a RAM disk. It is not intended for high-speed access, but can be useful for caching or buffering data from modules before writing to the SD card.


// ==========================================
// C++ Execution Layer (Hidden from C libraries)
// ==========================================
#ifdef __cplusplus
#include <cstdint>
#include <array>
#include <cstdio>
#include <cstdarg> 
#include <vector>
#include <string_view>
#include <iostream>
#include <string>
#include <vector>
#include "pico/stdlib.h"
#include "hardware/gpio.h"
#include "ff.h"       
#include "f_util.h"

/// @brief The namespace containing all helper functions and pin definition for arrays.
namespace Proteus
{
    constexpr std::array<std::uint8_t, 16> MODULE_GPIO = { 12, 13, 14, 15, 16, 17, 18, 19, 20, 21, 22, 23, 24, 25, 26, 27 };
    constexpr std::array<std::uint8_t, 4> CS_PINS = { 4, 5, 6, 7 };

    /// @brief Global FATFS instance for the SD card. This is used internally by the MountSDCard() helper, and can be used directly for advanced users who want more control over the filesystem. For most use cases, the simplified WriteFile() and ReadFile() helpers should be sufficient and you won't need to interact with this directly.
    inline FATFS StorageFS;
    inline FIL CurentFile; // Global FIL instance for the currently open file. This is used internally by the ReadFile() and WriteFile() helpers, but can be used directly for advanced users who want more control over file handling. 

    /// @brief Log severity levels for the logging system.
    enum LogLevel {
        LOG_ERROR,
        LOG_WARNING,
        LOG_INFO,
        LOG_DEBUG
    };

    /// @brief Helper to convert log level enum to a string prefix for log messages.
    /// @param level The severity level of the log message.
    /// @return The string prefix for the given log level. eg: "[ERROR] ", "[INFO]  ", etc.
    inline const std::string GetLevelString(LogLevel level) {
        switch (level) {
            case LOG_DEBUG:   return "[DEBUG]";
            case LOG_INFO:    return "[INFO]";
            case LOG_WARNING: return "[WARN]";
            case LOG_ERROR:   return "[ERROR]";
            default:          return "[LOG]";
        }
    }

    /// @brief Gets the current system timestamp string.
    /// @return The timestamp string, formatted as "(T+Xs.Yms)" where X is seconds and Y is milliseconds since boot.
    inline std::string GetTimestampString() {
        // Example using Pico's absolute uptime in milliseconds
        uint32_t uptime_ms = to_ms_since_boot(get_absolute_time());
        uint32_t seconds = uptime_ms / 1000;
        uint32_t ms = uptime_ms % 1000;
        return std::string("(T+") + std::to_string(seconds) + "s." + std::to_string(ms) + "ms)";
    }

    /// @brief Logs a message with a given severity level, using a printf-style format string and variable arguments.
    /// @param level The severity level of the log message.
    /// @param message The format string for the log message.
    /// @param args The variable arguments for the format string.
    /// @note Do not use this function directly. Use the Log(), LogError(), LogWarning(), LogInfo(), or LogDebug() helpers instead.
    inline void vLog(LogLevel level, const char* message, va_list args) {
        // 1. Clone the va_list because we need to read it twice (once to measure, once to format)
        va_list args_copy;
        va_copy(args_copy, args);

        // 2. Measure exactly how many characters are needed (passing NULL and 0)
        int length = vsnprintf(nullptr, 0, message, args_copy);
        va_end(args_copy);
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

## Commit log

2026-06-08 Created actually good readme
    [Monitoring.kicad_sch, Networking.kicad_sch, POE.kicad_sch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]
2026-06-09 Updated PCBs to use raw rp2040s
    [Virgil Motor.kicad_pcb, Virgil Motor.kicad_sch, Virgil Screen.kicad_pcb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]
2026-06-09 Finished PCBs
    [Combined.kicad_pcb, Networking.kicad_sch, Ribbon Adaptor.kicad_pcb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]
2026-06-15 Added Images to readme
    [Combined.kicad_pcb, Virgil Controller.kicad_pcb, Virgil Controller.kicad_pcb_bom.csv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]
2026-06-16 Started code, commiting before adding submodules
    [BoardConnector.kicad_sch, Panel.kicad_pcb, Ribbon Adaptor.kicad_pcb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]
2026-06-27 Added BOM, renamed projects
    [B3F-4055.step, BOM.csv, BoardConnector.kicad_sch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]
